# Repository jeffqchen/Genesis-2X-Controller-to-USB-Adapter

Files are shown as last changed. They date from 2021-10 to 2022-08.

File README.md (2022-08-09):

# Genesis 2X Controller to USB Adapter

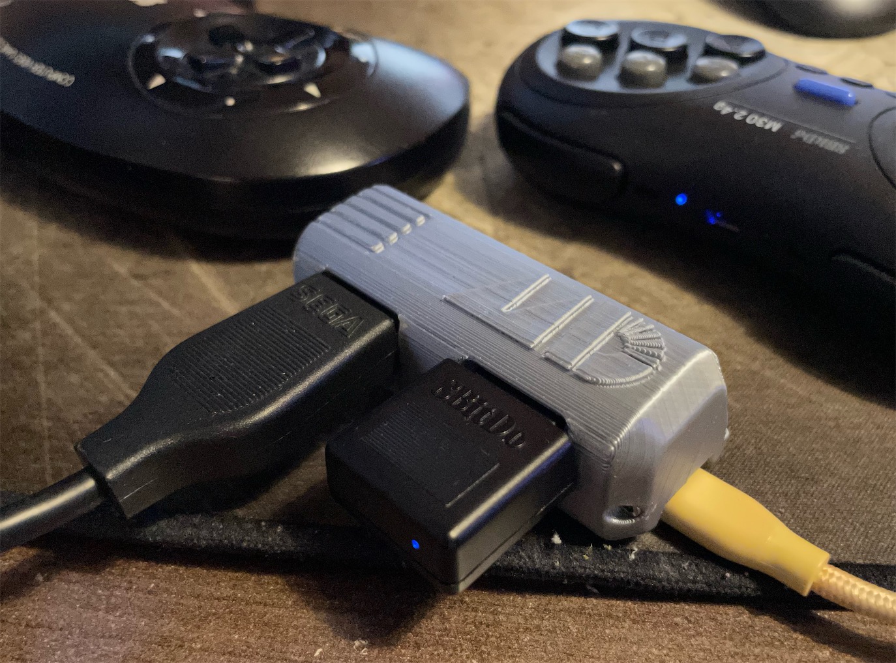
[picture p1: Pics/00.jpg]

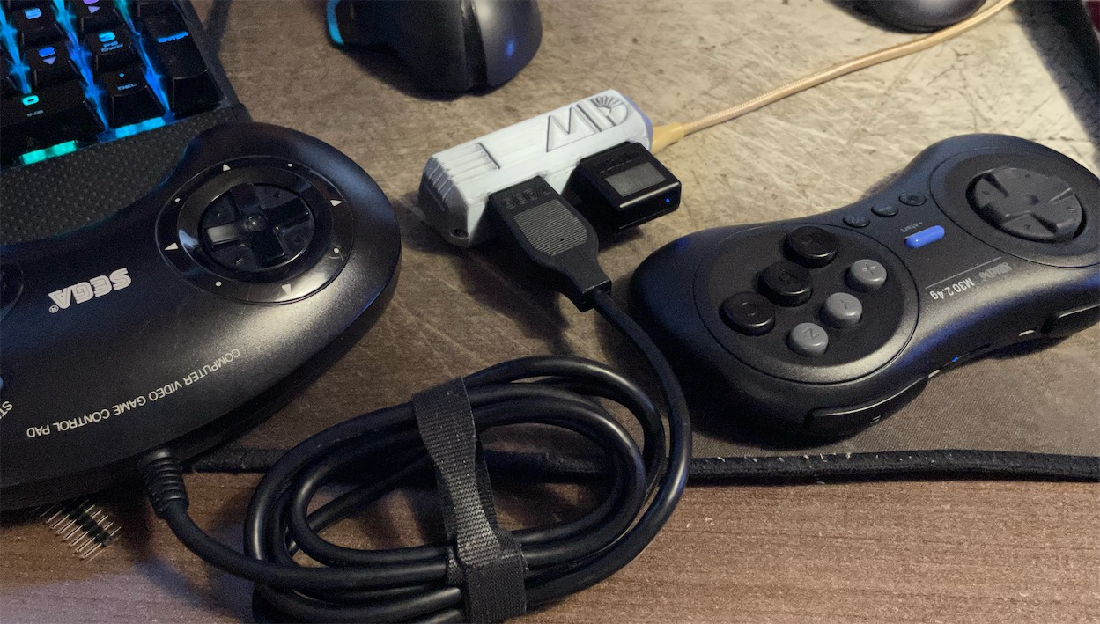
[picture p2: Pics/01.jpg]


This is my take on the Genesis 2X Controller to USB Adapter, powered by [DaemonBite](https://github.com/MickGyver/DaemonBite-Retro-Controllers-USB).

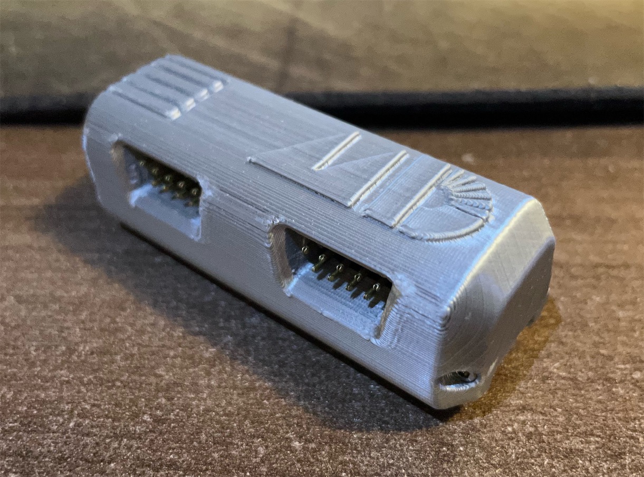
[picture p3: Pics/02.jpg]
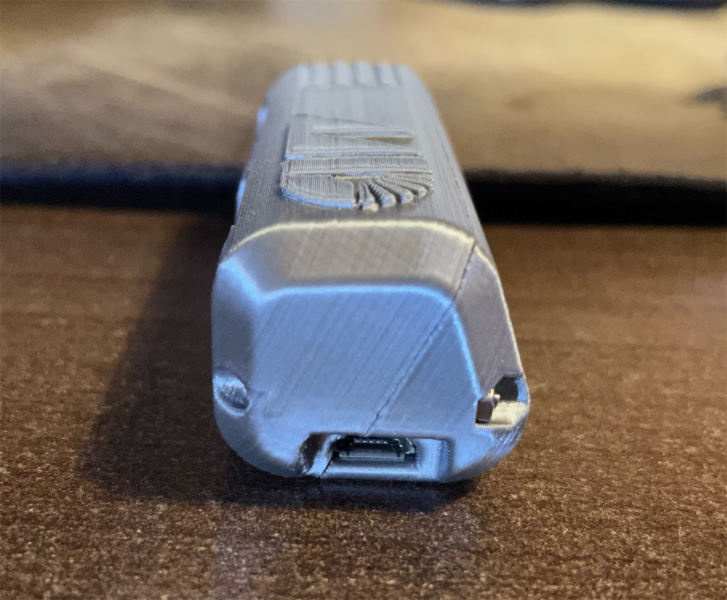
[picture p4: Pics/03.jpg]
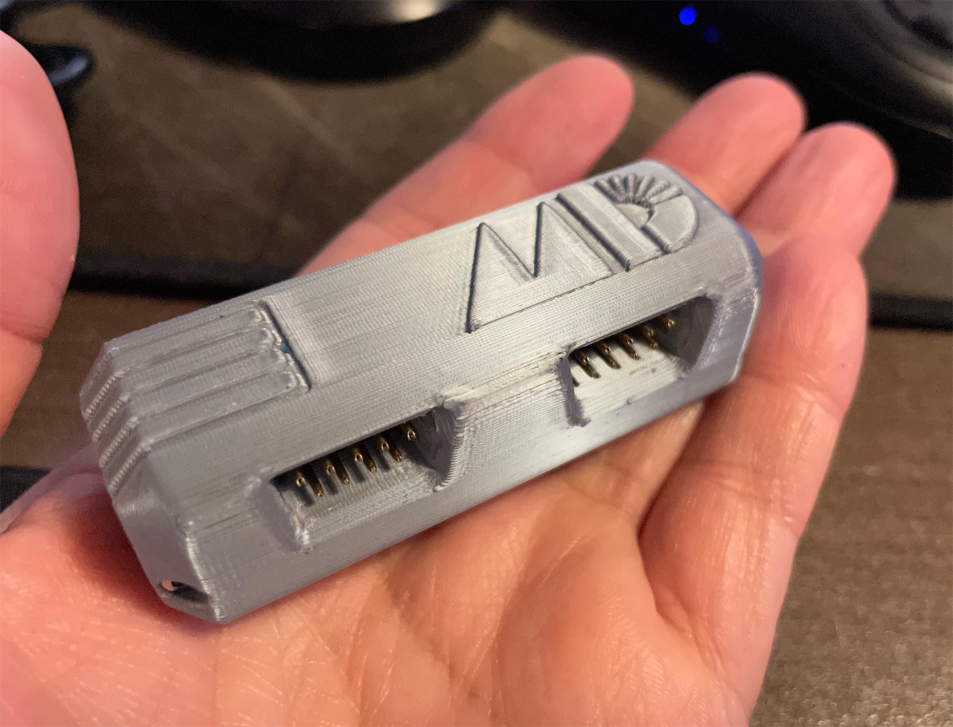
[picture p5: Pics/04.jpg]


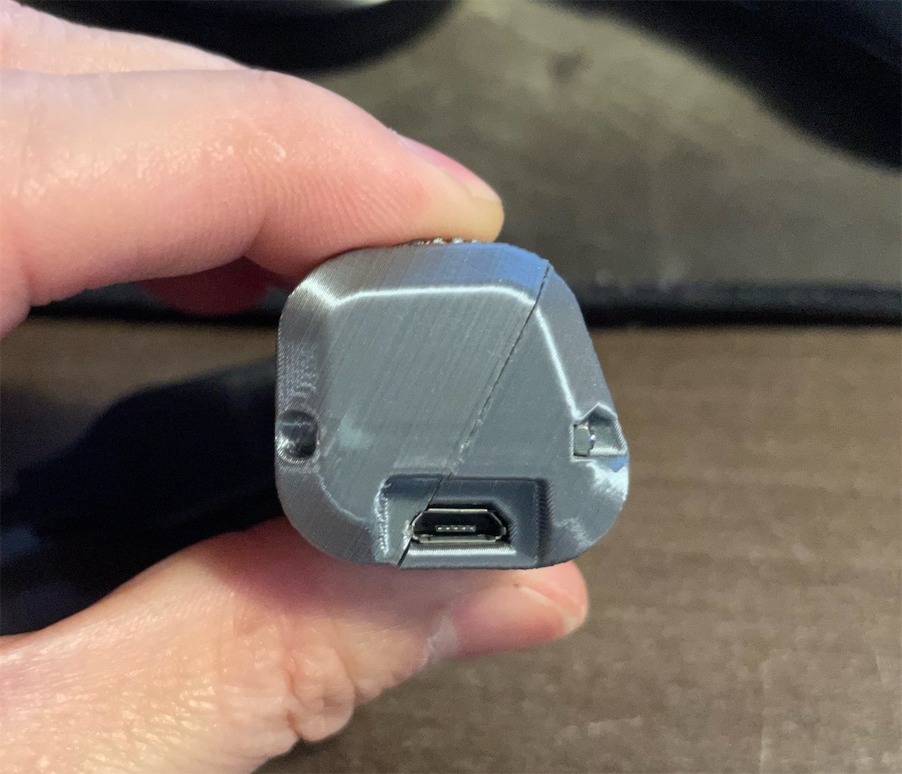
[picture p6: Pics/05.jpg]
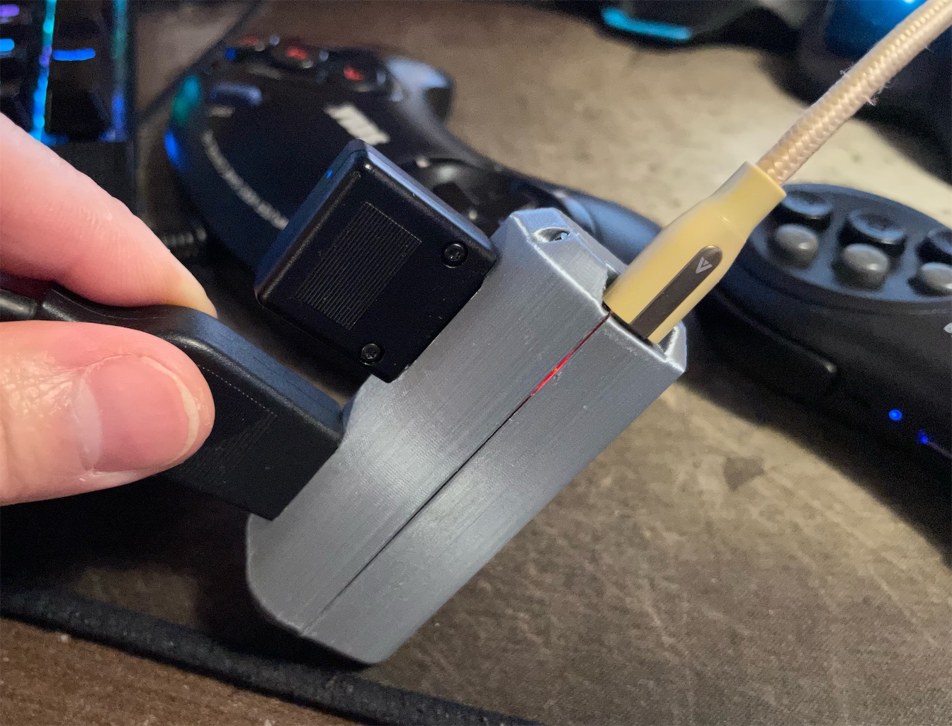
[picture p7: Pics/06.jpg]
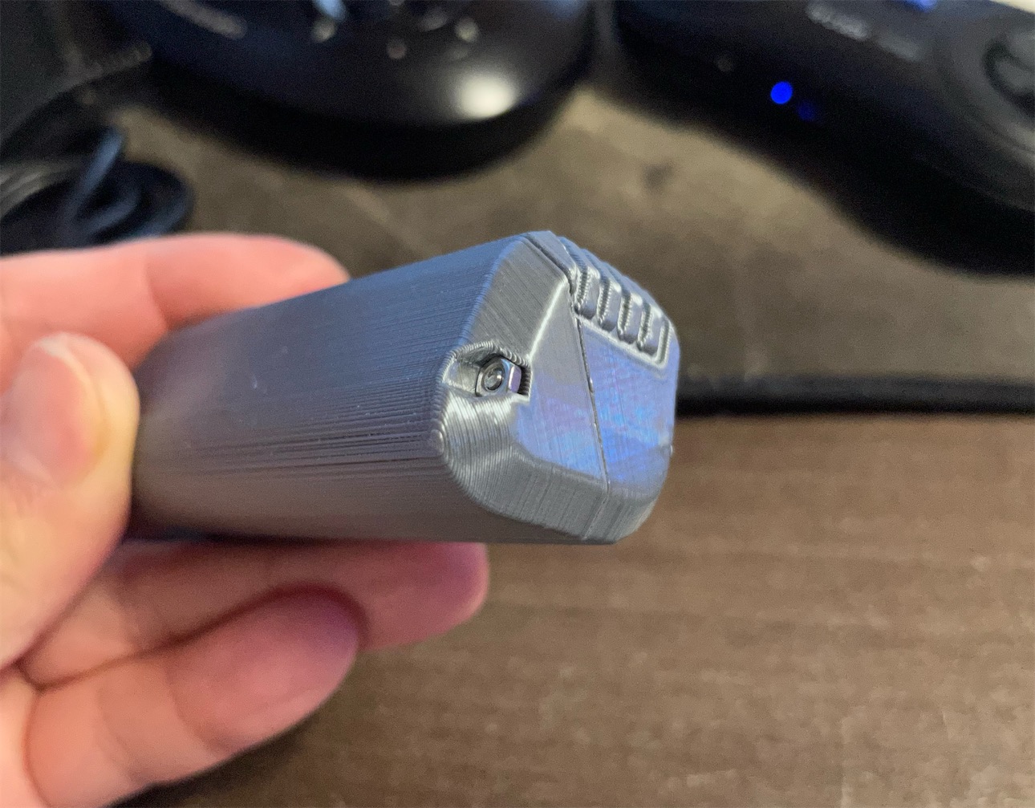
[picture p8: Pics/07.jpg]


----------

## Parts

- [PCB](https://oshpark.com/shared_projects/lUJ4HBFS)

- DB9 Ports (Choose the DR9, Male option) - [Link](https://github.com/jeffqchen/JeffParts/blob/main/Connectors/DB9/Male%20PCB/info.md)

- Arduino Pro Micro 5V/16MHz Version - [Link](https://github.com/jeffqchen/JeffParts/blob/main/Board/Arduino/Pro%20Micro/5V%2016MHz/info.md)

- [2x] 2.54mm Pitch Pin Header, Square Pins, Single Row - 12 pins on each side - [Link](https://github.com/jeffqchen/JeffParts/blob/main/Connectors/Pin%20Header/2.54mm%20Pitch/Male%20Straight/info.md)

- [2x] M2x20mm Hex Screw & Nut - [Link](https://github.com/jeffqchen/JeffParts/blob/main/Parts/M2%20M3%20Hex%20Screw%20%26%20Nut/info.md)

- 3D Printed Shell

---------

## 3D Printing

Print the two halves of the shell in their original orientation.

Suggested settings:
- 0.16 layer height
- 0.35 line width
- With support

-----------

## Assembly

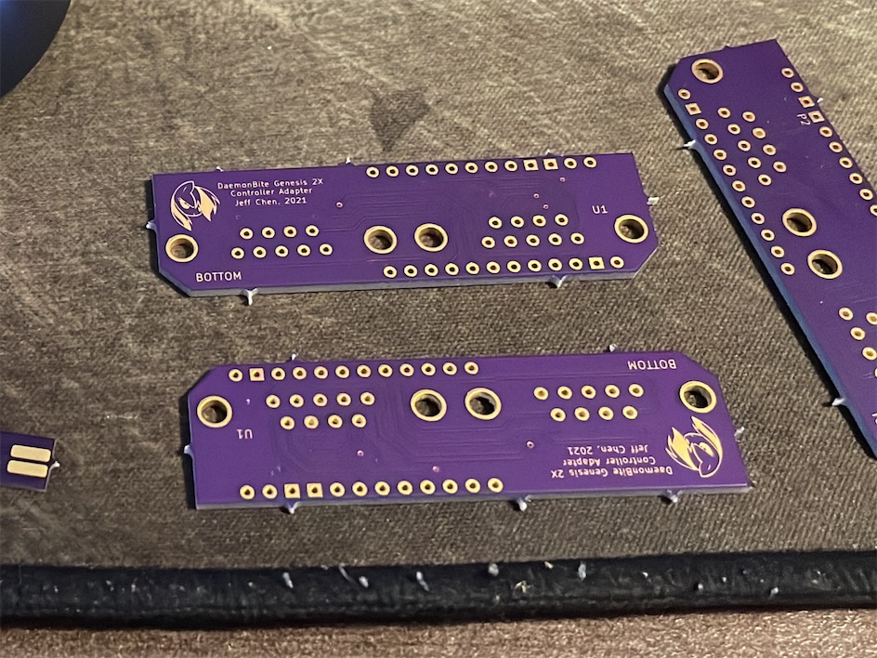
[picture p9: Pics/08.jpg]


Trim all the extra stubs from the PCB.

Loosen the screws on both sides of the DB9 ports, but don't remove them yet.

Solder in the DB9 ports first. Then the Pro Micro on the other side with the pin headers. Trim the protruding pin header pins on the other side of the PCB. Otherwise you won't be able to fit the assembly into the shell.

Remove the screws and the face plate from the DB9 port. Otherwise you won't be able to fit the assembly into the shell.

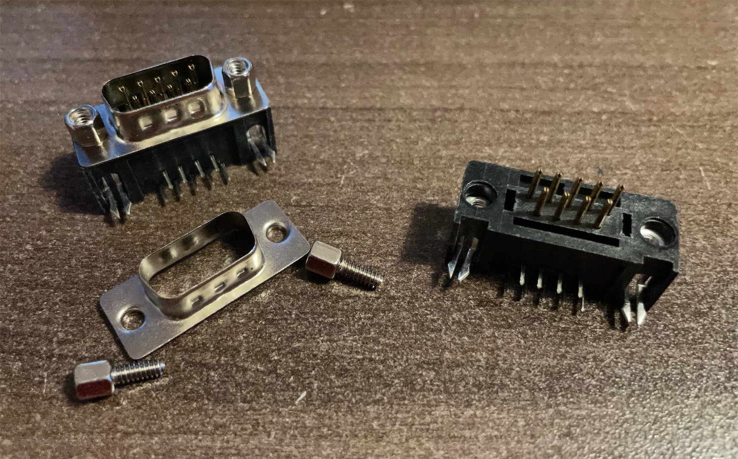
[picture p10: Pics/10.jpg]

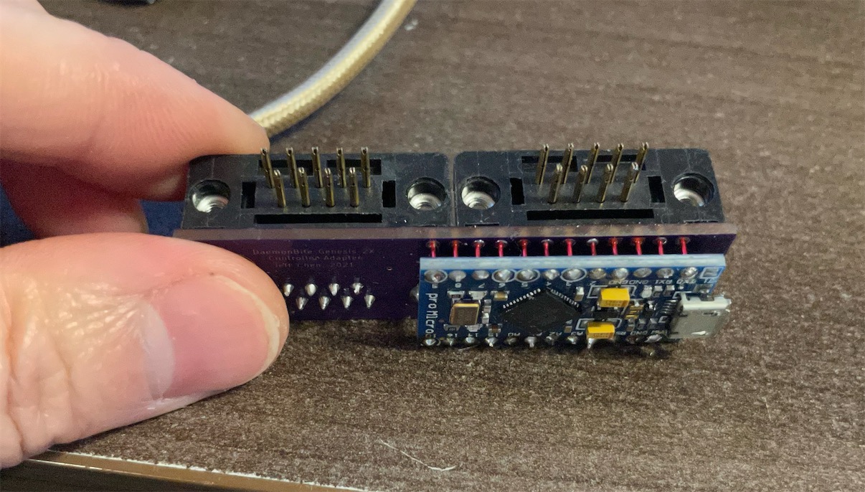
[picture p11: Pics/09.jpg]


Finally, slide the assembly into the printed shell, and screw it shut with two sets of M2x20mm hex screws and nuts.

-----------
Shield: [][cc-by-sa]

This work is licensed under a
[Creative Commons Attribution-ShareAlike 4.0 International License][cc-by-sa].

[][cc-by-sa]

[cc-by-sa]: http://creativecommons.org/licenses/by-sa/4.0/
[cc-by-sa-image]: https://licensebuttons.net/l/by-sa/4.0/88x31.png
[cc-by-sa-shield]: https://img.shields.io/badge/License-CC%20BY--SA%204.0-lightgrey.svg

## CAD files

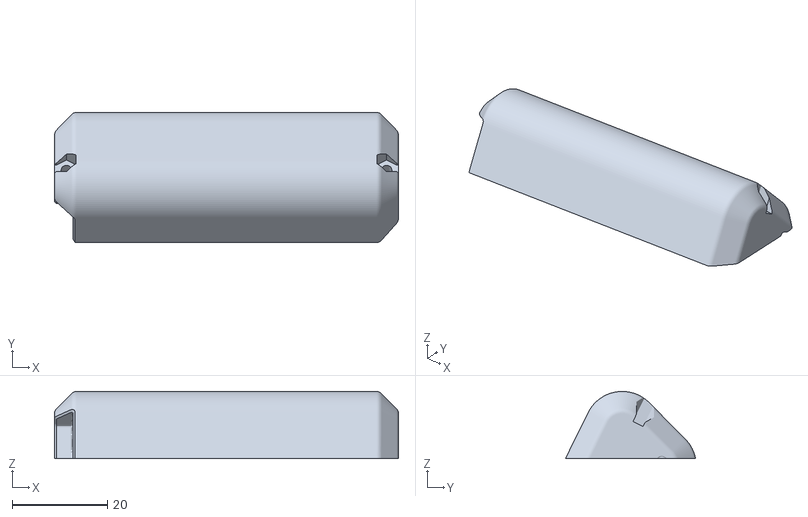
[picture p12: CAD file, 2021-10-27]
3D Print/Bottom.stl
72.1 x 27.3 x 14.1

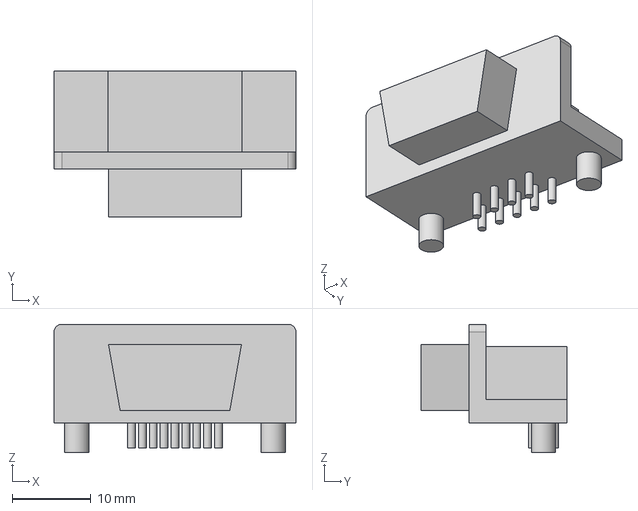
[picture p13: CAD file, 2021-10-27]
KiCAD/DaemonBite_MD2/Files/DE-09 Male PCB.step
30.8 x 18.6 x 16.4 mm

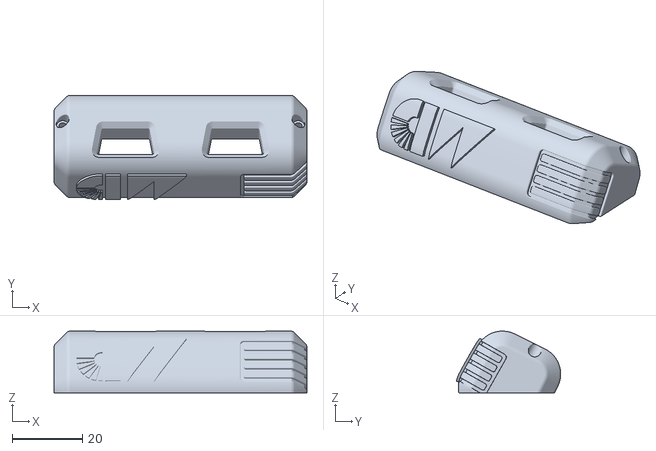
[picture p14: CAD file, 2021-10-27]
3D Print/Top.stl
72.1 x 29.7 x 17.6

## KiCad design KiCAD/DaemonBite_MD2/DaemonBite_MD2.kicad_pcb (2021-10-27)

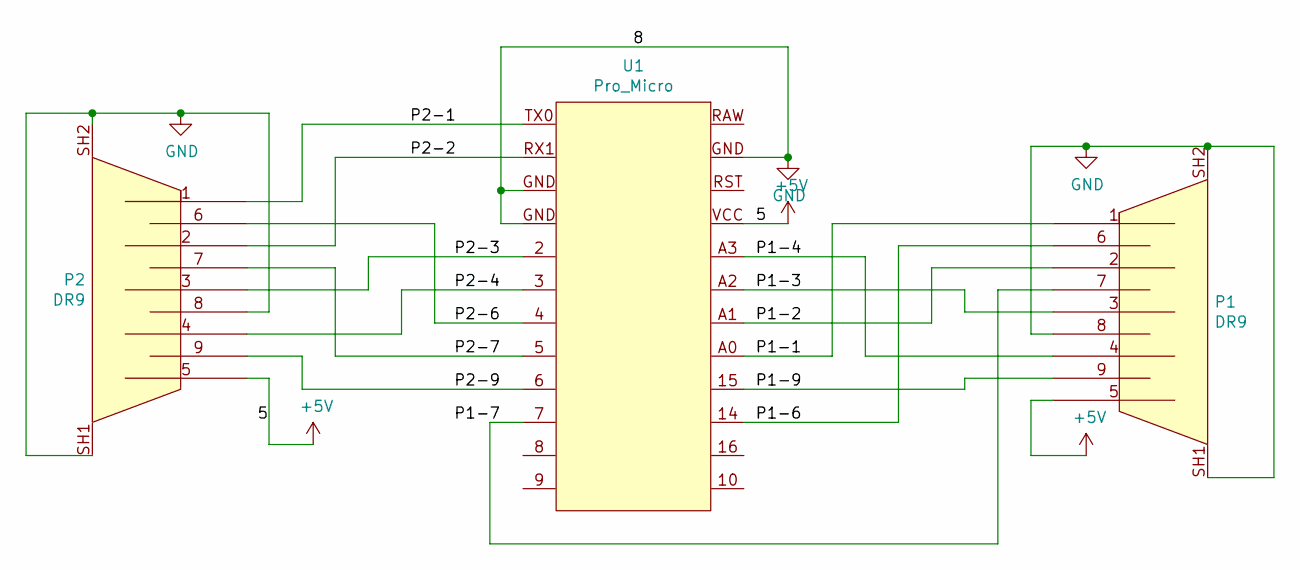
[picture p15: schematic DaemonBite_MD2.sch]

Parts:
P1, P2: DR9; DR9_Male_PCB
U1: Pro_Micro

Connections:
+5V: P1.5, P2.5, U1.VCC
/P1-1: P1.1, U1.A0
/P1-2: P1.2, U1.A1
/P1-3: P1.3, U1.A2
/P1-4: P1.4, U1.A3
/P1-6: P1.6, U1.14
/P1-7: P1.7, U1.7
/P1-9: P1.9, U1.15
/P2-1: P2.1, U1.TX0
/P2-2: P2.2, U1.RX1
/P2-3: P2.3, U1.2
/P2-4: P2.4, U1.3
/P2-6: P2.6, U1.4
/P2-7: P2.7, U1.5
/P2-9: P2.9, U1.6
GND: P1.8, P1.SH1, P1.SH2, P2.8, P2.SH1, P2.SH2, U1.GND

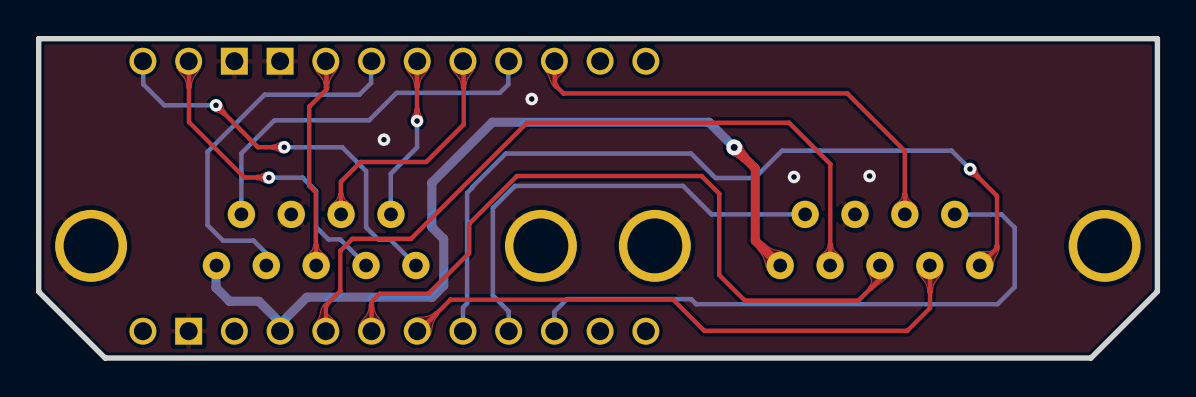
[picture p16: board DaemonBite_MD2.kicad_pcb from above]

Board: 2 copper layers, 62.2 x 17.7 mm, 3 parts (1 on the bottom side), 16 nets.

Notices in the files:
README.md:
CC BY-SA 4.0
